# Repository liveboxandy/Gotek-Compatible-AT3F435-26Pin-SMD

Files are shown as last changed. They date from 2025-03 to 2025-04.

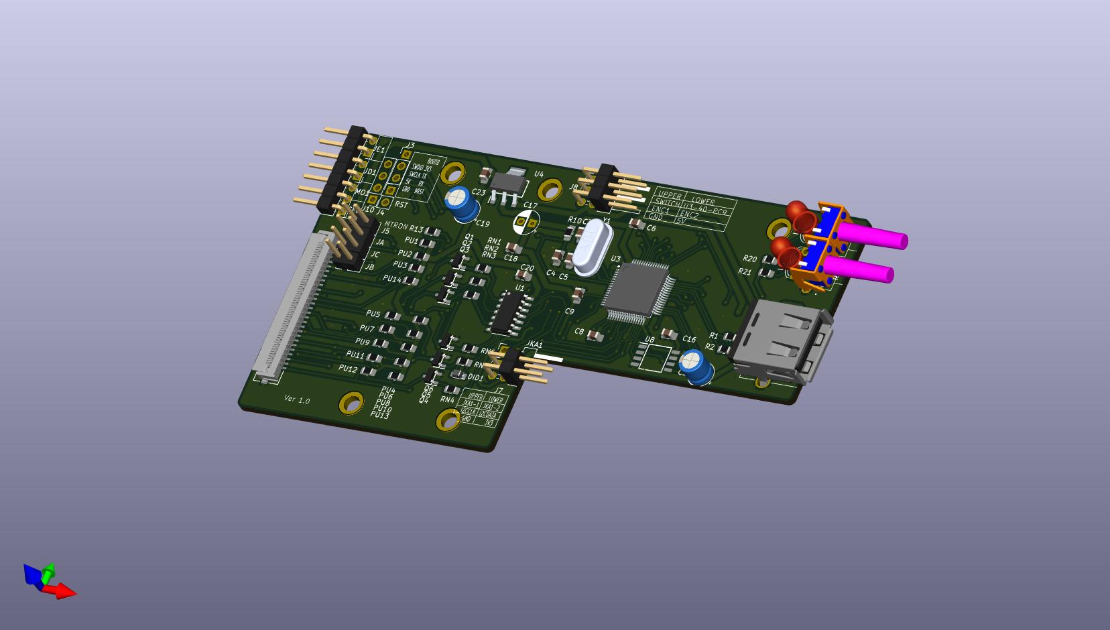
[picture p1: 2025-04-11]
Gotek.jpg

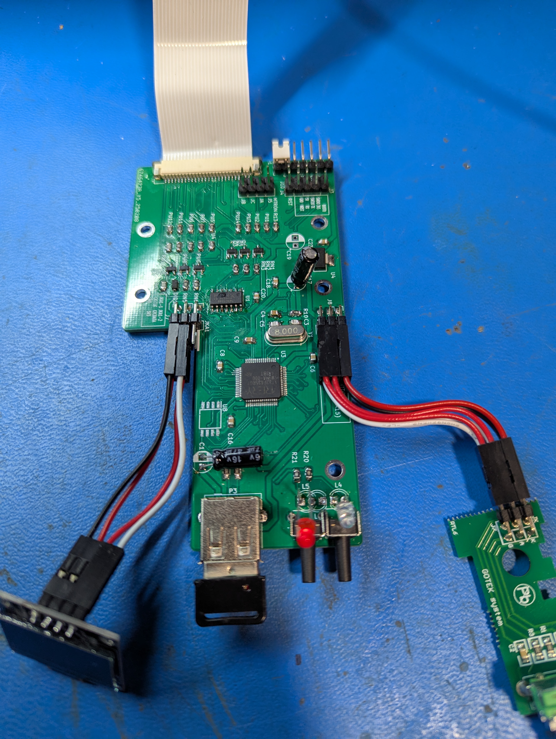
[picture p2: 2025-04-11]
Pictures/AT32F435RGT7.jpg

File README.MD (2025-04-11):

Initial schematic and gerbers for a Gotek(?) compatible with an Artery AT32F435RGT7 chip and a 26 Pin FFC connector.
Used SFRKC30.AT4.35 PCB for most of the schematic and layout but used SFRC2D.B PCB for the 26 Pin FFC connections.
Used photographs and a multimeter along with removing U1 and U3 on the SFRKC30.AT4.35 to get to the traces underneath.
Where possible I followed the original PCB routing of the SFRKC30.AT4.35 but Kicad has some different rules for trace widths (between pins 5&6 of U8 which isn't fitted).

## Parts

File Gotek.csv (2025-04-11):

Source: | W:\Emulators\Spectrum Repair\Gotek Bits\Gotek AT32F435 26 Pin Std Size PCB\Gotek.kicad_sch
Date: | 2025-04-11T10:23:15+0100
Tool: | Eeschema 8.0.9
Generator: | C:\Program Files\KiCad\7.0\bin\scripting\plugins/bom_csv_grouped_by_value.py
Component Count: | 72
Collated Components:
Item | Qty | Reference(s) | Value | LibPart | Footprint | Datasheet | DNP | Arrow Part Number | Arrow Price/Stock | Datasheet | Description | Footprint | Height | Manufacturer_Name | Manufacturer_Part_Number | Mouser Part Number | Mouser Price/Stock | Sim.Device | Sim.Pins
1 | 2 | C1, C19 | 100uF | Device:C_Polarized | Capacitor_THT:CP_Radial_D5.0mm_P2.50mm | ~ |  |  |  | ~ | Polarized capacitor | Capacitor_THT:CP_Radial_D5.0mm_P2.50mm
2 | 2 | C3, C5 | 22pF | Device:C | Capacitor_SMD:C_0805_2012Metric_Pad1.18x1.45mm_HandSolder | ~ |  |  |  | ~ | Unpolarized capacitor | Capacitor_SMD:C_0805_2012Metric_Pad1.18x1.45mm_HandSolder
3 | 8 | C4, C6, C8, C9, C16, C18, C20, C23 | 100nF | Device:C | Capacitor_SMD:C_0805_2012Metric_Pad1.18x1.45mm_HandSolder | ~ |  |  |  | ~ | Unpolarized capacitor | Capacitor_SMD:C_0805_2012Metric_Pad1.18x1.45mm_HandSolder
4 | 1 | C17 | 100uF | Device:C_Polarized | Capacitor_THT:CP_Radial_D5.0mm_P2.50mm | ~ | DNP |  |  | ~ | Polarized capacitor | Capacitor_THT:CP_Radial_D5.0mm_P2.50mm
5 | 1 | DID1 | 1N4148WS | Diode:1N4148WS | Gotek:SODFL2512X90N | https://www.vishay.com/docs/85751/1n4148ws.pdf |  |  |  | https://www.vishay.com/docs/85751/1n4148ws.pdf | 75V 0.15A Fast switching Diode, SOD-323 | Gotek:SODFL2512X90N |  |  |  |  |  | D | 1=K 2=A
6 | 1 | J3 | Conn_01x03_Pin | Connector:Conn_01x03_Pin | Connector_PinHeader_2.54mm:PinHeader_1x03_P2.54mm_Vertical | ~ | DNP |  |  | ~ | Generic connector, single row, 01x03, script generated | Connector_PinHeader_2.54mm:PinHeader_1x03_P2.54mm_Vertical
7 | 1 | J4 | Conn_01x02_Pin | Connector:Conn_01x02_Pin | Connector_PinHeader_2.54mm:PinHeader_1x02_P2.54mm_Vertical | ~ | DNP |  |  | ~ | Generic connector, single row, 01x02, script generated | Connector_PinHeader_2.54mm:PinHeader_1x02_P2.54mm_Vertical
8 | 4 | J5, JA1, JB1, JC1 | Conn_01x02 | Connector:Conn_01x02_Pin | Connector_PinHeader_2.54mm:PinHeader_1x02_P2.54mm_Vertical | ~ |  |  |  | ~ | Generic connector, single row, 01x02, script generated | Connector_PinHeader_2.54mm:PinHeader_1x02_P2.54mm_Vertical
9 | 1 | J7 | OLED | Connector:Conn_01x04_Pin | Connector_PinHeader_2.54mm:PinHeader_2x02_P2.54mm_Horizontal | ~ |  |  |  | ~ | Generic connector, single row, 01x04, script generated | Connector_PinHeader_2.54mm:PinHeader_2x02_P2.54mm_Horizontal
10 | 1 | J8 | RotaryEncoder | Connector:Conn_01x04_Pin | Connector_PinHeader_2.54mm:PinHeader_2x02_P2.54mm_Horizontal | ~ |  |  |  | ~ | Generic connector, single row, 01x04, script generated | Connector_PinHeader_2.54mm:PinHeader_2x02_P2.54mm_Horizontal
11 | 1 | J10 | Conn_01x04_Pin | Connector:Conn_01x04_Pin | Connector_PinHeader_2.54mm:PinHeader_1x04_P2.54mm_Vertical | ~ | DNP |  |  | ~ | Generic connector, single row, 01x04, script generated | Connector_PinHeader_2.54mm:PinHeader_1x04_P2.54mm_Vertical
12 | 2 | JD1, JE1 | Conn_01x02_Pin | Connector:Conn_01x02_Pin | Connector_PinHeader_2.54mm:PinHeader_1x02_P2.54mm_Horizontal | ~ |  |  |  | ~ | Generic connector, single row, 01x02, script generated | Connector_PinHeader_2.54mm:PinHeader_1x02_P2.54mm_Horizontal
13 | 1 | JK1 | Conn_01x02 | Connector:Conn_01x02_Pin | Connector_PinHeader_2.54mm:PinHeader_2x01_P2.54mm_Horizontal | ~ |  |  |  | ~ | Generic connector, single row, 01x02, script generated | Connector_PinHeader_2.54mm:PinHeader_2x01_P2.54mm_Horizontal
14 | 1 | JKA1 | Conn_01x02 | Connector:Conn_01x02_Pin | Connector_PinHeader_2.54mm:PinHeader_2x01_P2.54mm_Horizontal | ~ | DNP |  |  | ~ | Generic connector, single row, 01x02, script generated | Connector_PinHeader_2.54mm:PinHeader_2x01_P2.54mm_Horizontal
15 | 1 | L3 | LED GREEN | Device:LED | LED_THT:LED_D4.0mm | ~ | DNP |  |  | ~ | Light emitting diode | LED_THT:LED_D4.0mm
16 | 1 | L4 | LED GREEN | Device:LED | LED_THT:LED_D4.0mm | ~ |  |  |  | ~ | Light emitting diode | LED_THT:LED_D4.0mm
17 | 1 | L5 | LED RED | Device:LED | LED_THT:LED_D4.0mm | ~ |  |  |  | ~ | Light emitting diode | LED_THT:LED_D4.0mm
18 | 1 | MO1 | Conn_01x03_Pin | Connector:Conn_01x03_Pin | Connector_PinHeader_2.54mm:PinHeader_1x03_P2.54mm_Horizontal | ~ |  |  |  | ~ | Generic connector, single row, 01x03, script generated | Connector_PinHeader_2.54mm:PinHeader_1x03_P2.54mm_Horizontal
19 | 1 | P1 | 2005280260 | Gotek:2005280260 | Gotek:MOLEX_CON_2005280260 | 2005280260 |  |  |  | 2005280260 |  | Gotek:MOLEX_CON_2005280260
20 | 1 | P3 | USB_A | Connector:USB_A | Connector_USB:USB_A_Molex_67643_Horizontal | ~ |  |  |  | ~ | USB Type A connector | Connector_USB:USB_A_Molex_67643_Horizontal
21 | 21 | PU1, PU2, PU3, PU4, PU5, PU6, PU7, PU8, PU9, PU10, PU11, PU12, PU13, PU14, R20, RN1, RN2, RN3, RN4, RN5, RN6 | 1K | Device:R | Resistor_SMD:R_0805_2012Metric_Pad1.20x1.40mm_HandSolder | ~ |  |  |  | ~ | Resistor | Resistor_SMD:R_0805_2012Metric_Pad1.20x1.40mm_HandSolder
22 | 6 | Q1, Q2, Q3, Q4, Q5, Q6 | PMBT2222A,215 | Gotek:PMBT2222A,215 | Gotek:SOT95P280X130-3N | https://assets.nexperia.com/documents/data-sheet/PMBT2222A.pdf |  |  |  | https://assets.nexperia.com/documents/data-sheet/PMBT2222A.pdf | PMBT2222; PMBT2222A - NPN switching transistors | Gotek:SOT95P280X130-3N | 1.1 | Nexperia | PMBT2222A,215 | 771-PMBT2222A-T/R | https://www.mouser.co.uk/ProductDetail/Nexperia/PMBT2222A215?qs=LOCUfHb8d9u7n2jbGrJFWg%3D%3D
23 | 2 | R1, R2 | 22R | Device:R | Resistor_SMD:R_0805_2012Metric_Pad1.20x1.40mm_HandSolder | ~ |  |  |  | ~ | Resistor | Resistor_SMD:R_0805_2012Metric_Pad1.20x1.40mm_HandSolder
24 | 2 | R10, R13 | 4K7 | Device:R | Resistor_SMD:R_0805_2012Metric_Pad1.20x1.40mm_HandSolder | ~ |  |  |  | ~ | Resistor | Resistor_SMD:R_0805_2012Metric_Pad1.20x1.40mm_HandSolder
25 | 1 | R21 | 12K | Device:R | Resistor_SMD:R_0805_2012Metric_Pad1.20x1.40mm_HandSolder | ~ |  |  |  | ~ | Resistor | Resistor_SMD:R_0805_2012Metric_Pad1.20x1.40mm_HandSolder
26 | 2 | S3, S4 | SKHHANA010 | Gotek:SKHHANA010 | Gotek:SKHHLQA010 | https://www.mouser.co.uk/datasheet/2/15/SKHH-1370651.pdf |  |  |  | https://www.mouser.co.uk/datasheet/2/15/SKHH-1370651.pdf | Tact switch,PCB,SPST,black,0.98N o/force Black Stem Tactile Switch, SPST-NO 50 mA 9.5mm | Gotek:SKHHLQA010 |  | ALPS Electric | SKHHANA010 | 688-SKHHAN | https://www.mouser.co.uk/ProductDetail/Alps-Alpine/SKHHANA010?qs=seHrhfPpLDzbQApxfd3mfQ%3D%3D
27 | 1 | U1 | 74AHC04 | 74xx:74AHC04 | Package_SO:SO-14_3.9x8.65mm_P1.27mm | https://assets.nexperia.com/documents/data-sheet/74AHC_AHCT04.pdf |  |  |  | https://assets.nexperia.com/documents/data-sheet/74AHC_AHCT04.pdf | Hex Inverter | Package_SO:SO-14_3.9x8.65mm_P1.27mm
28 | 1 | U3 | AT32F435RGT7 | Gotek:AT32F435RxT7-SQ | Gotek:QFP50P1200X1200X160-64N | https://www.arterychip.com/file/download/1977 |  |  |  | https://www.arterychip.com/file/download/1977 | 32-Bit FLASH ARM Cortex-M4 200MHz 2.6V ~ 3.6V LQFP-64 ARTERY Mcu RoHS | Gotek:QFP50P1200X1200X160-64N | 1.6 | Artery | AT32F435RGT7
29 | 1 | U4 | AMS1117-3.3 | Gotek:ams1117-3.3v | Gotek:SOT229P700X180-4N | http://www.advanced-monolithic.com/pdf/ds1117.pdf |  |  |  | http://www.advanced-monolithic.com/pdf/ds1117.pdf | 1A LOW DROPOUT VOLTAGE REGULATOR, SOT-223 | Gotek:SOT229P700X180-4N | 1.8 | Advanced Monolithic Systems | ams1117-3.3v
30 | 1 | U8 | SST25VF016B-50-4C-S2AF | Gotek:SST25VF016B-50-4C-S2AF | Gotek:SOIC127P790X216-8N | https://ww1.microchip.com/downloads/en/DeviceDoc/20005044C.pdf | DNP |  |  | https://ww1.microchip.com/downloads/en/DeviceDoc/20005044C.pdf | MICROCHIP - SST25VF016B-50-4C-S2AF - Flash Memory, Serial NOR, 16 Mbit, SPI, SOIC, 8 Pins | Gotek:SOIC127P790X216-8N | 2.16 | Microchip | SST25VF016B-50-4C-S2AF | 579-25VF016B504CS2AF | https://www.mouser.co.uk/ProductDetail/Microchip-Technology-Atmel/SST25VF016B-50-4C-S2AF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
31 | 1 | Y1 | 8Mhz | Device:Crystal | Crystal:Crystal_HC18-U_Vertical | ~ |  |  |  | ~ | Two pin crystal | Crystal:Crystal_HC18-U_Vertical

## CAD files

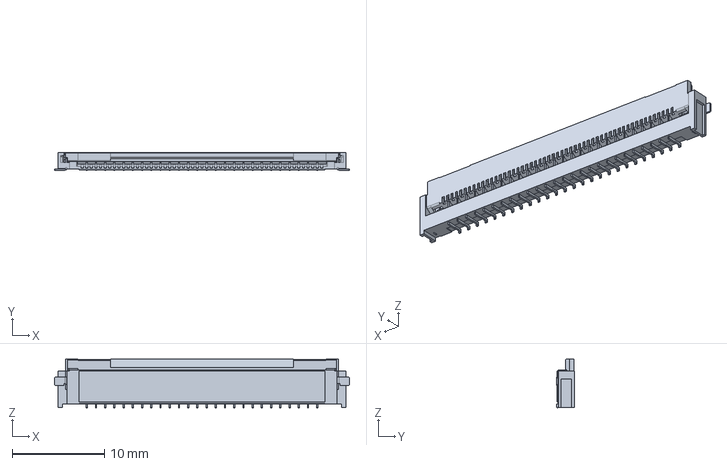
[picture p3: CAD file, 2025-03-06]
MOD/Molex 2005280260.stp
32.0 x 1.90 x 5.30 mm

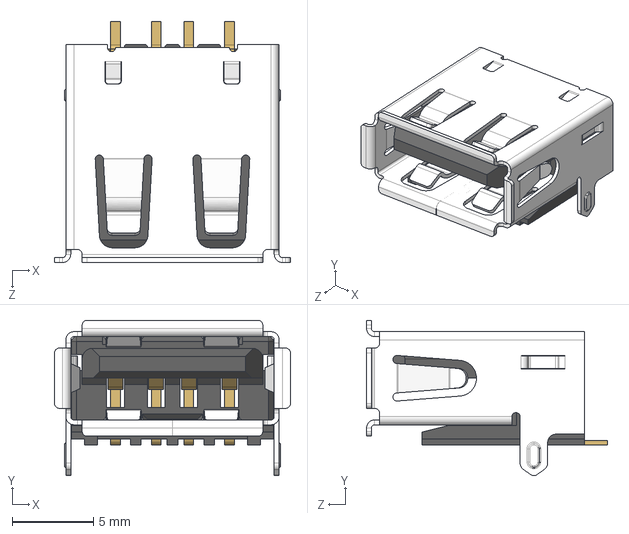
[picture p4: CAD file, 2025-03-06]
MOD/USB1046-GF-0190-L-B-A.stp
14.5 x 9.55 x 14.8 mm

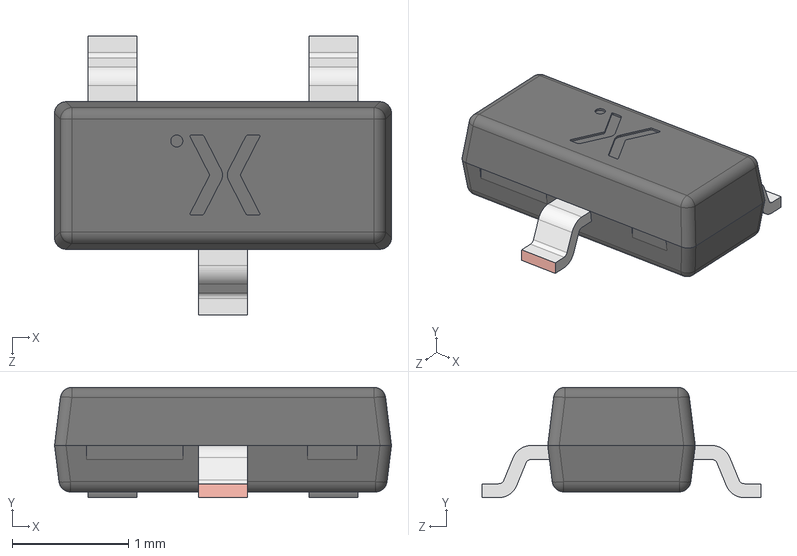
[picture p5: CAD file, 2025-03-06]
MOD/PMBT2222A,215.stp
2.90 x 0.95 x 2.40 mm
SOT23 lower body
SOT23 Lead x 3
SOT23 Upper body

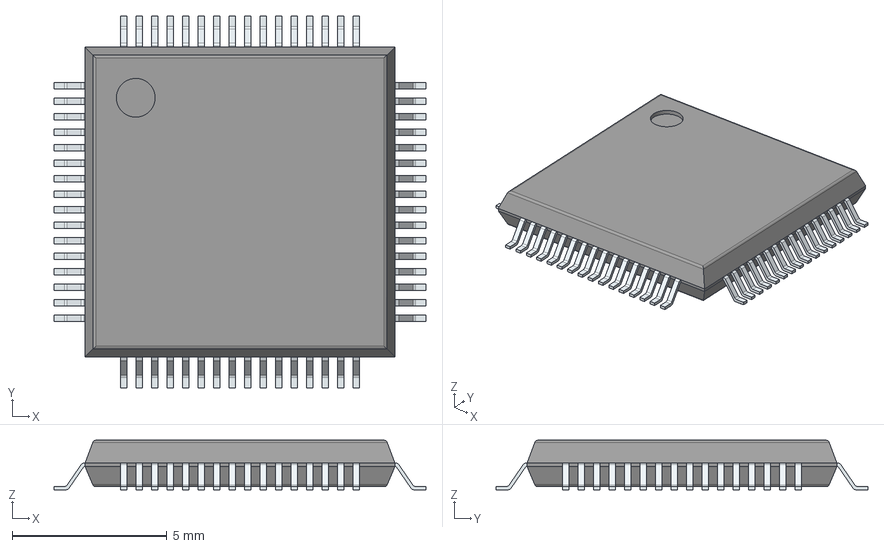
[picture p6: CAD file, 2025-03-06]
MOD/AT32F415RxT7.stp
12.0 x 12.0 x 1.60 mm
PinsArrayLR
PinsArrayTB

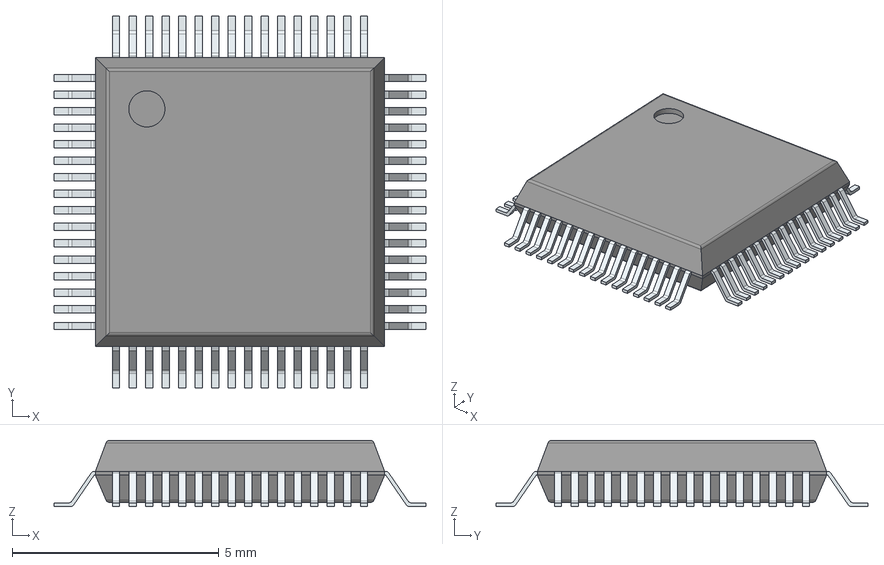
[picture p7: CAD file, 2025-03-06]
MOD/at32f415rct7.stp
9.00 x 9.00 x 1.60 mm
PinsArrayLR
PinsArrayTB

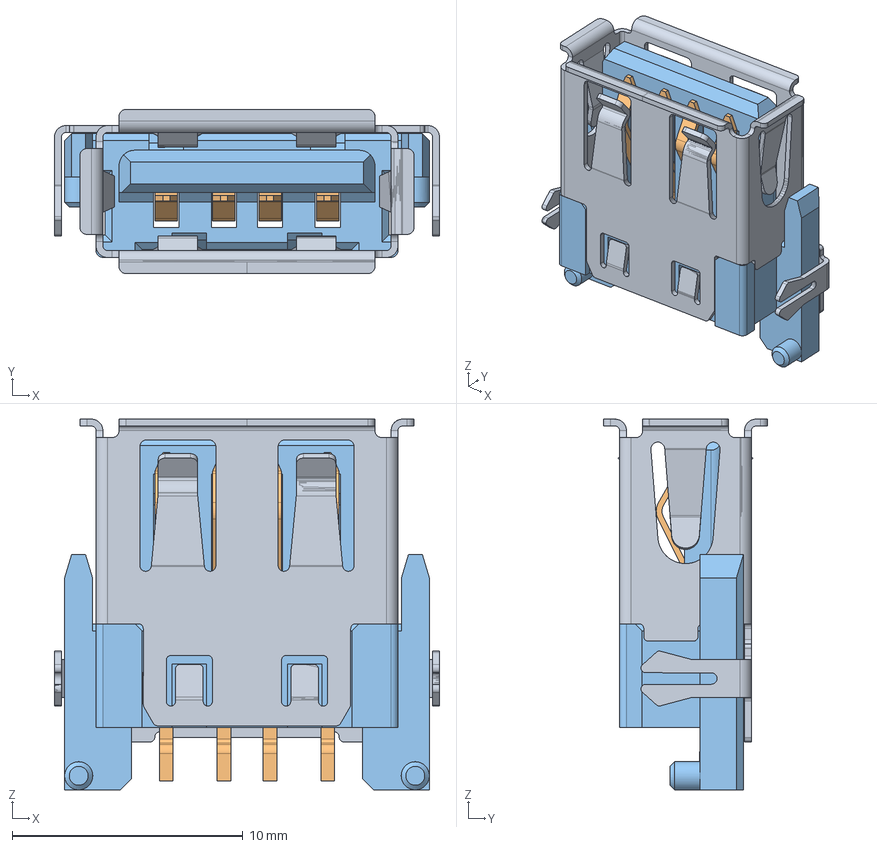
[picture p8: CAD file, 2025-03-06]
MOD/USB1055-GF-L-A.stp
16.7 x 7.12 x 16.1 mm
USB1055-GF-L-A_PART8
USB1055-GF-L-A_PART7
USB1055-GF-L-A_PART6
USB1055-GF-L-A_PART5
USB1055-GF-L-A_PART4
USB1055-GF-L-A_PART3
USB1055-GF-L-A_PART2
USB1055-GF-L-A_PART1

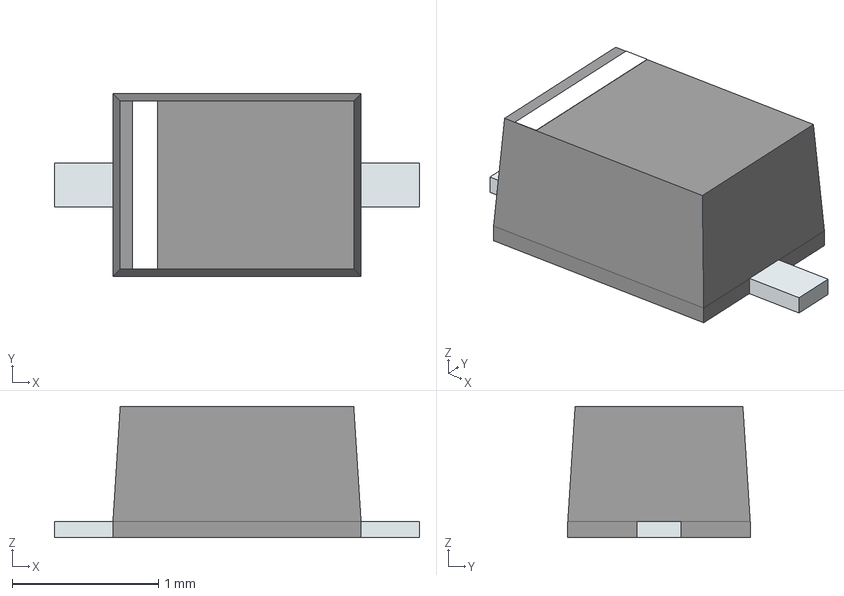
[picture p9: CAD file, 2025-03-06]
MOD/1N4148WS.stp
2.50 x 1.25 x 0.9 mm
PinKIdent
PinK
PinA

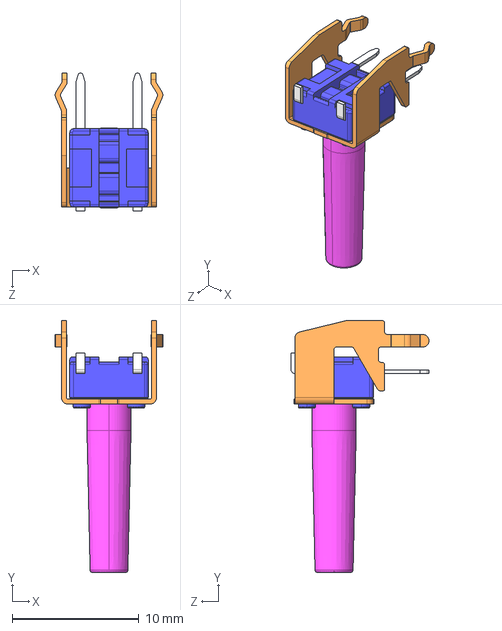
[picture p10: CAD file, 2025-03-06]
MOD/SKHHNK.STEP
8.50 x 19.9 x 10.9 mm

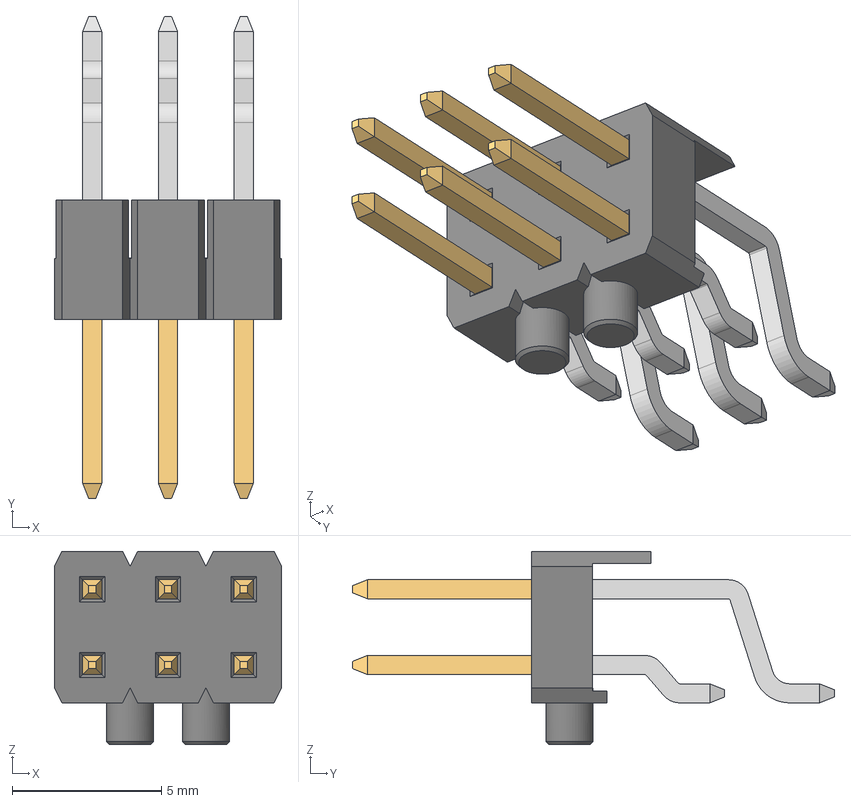
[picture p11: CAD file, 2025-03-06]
MOD/6101XX249121_610106249121.step
7.62 x 16.2 x 6.48 mm
6100xx249121_PIN LONGUE x 3
6100xx249121_PIN COURTE x 3

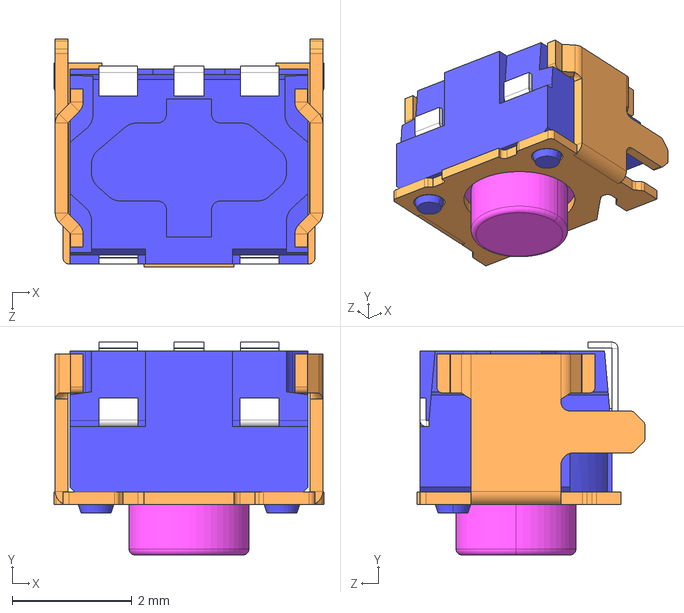
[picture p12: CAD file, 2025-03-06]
MOD/SKRTLAE010.stp
4.50 x 3.55 x 3.80 mm

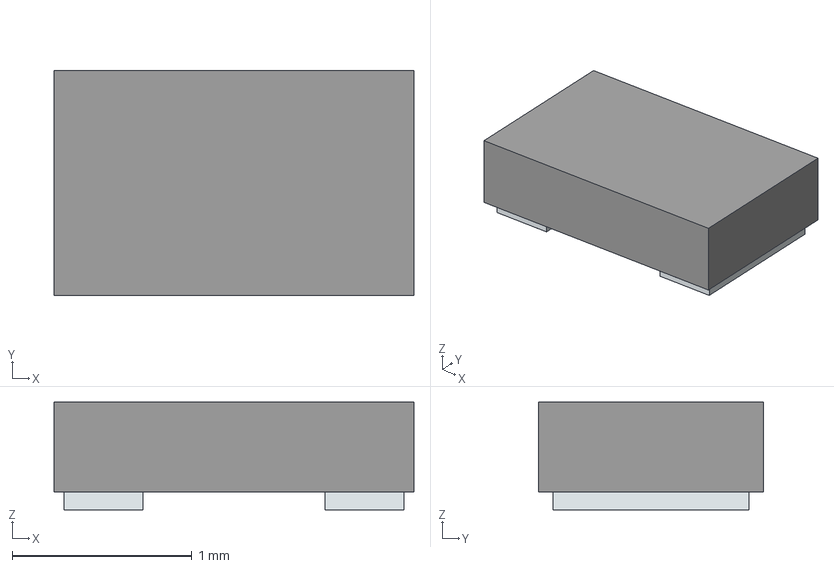
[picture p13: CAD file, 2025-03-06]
MOD/HSMC-C177.stp
2.00 x 1.25 x 0.6 mm
Pins

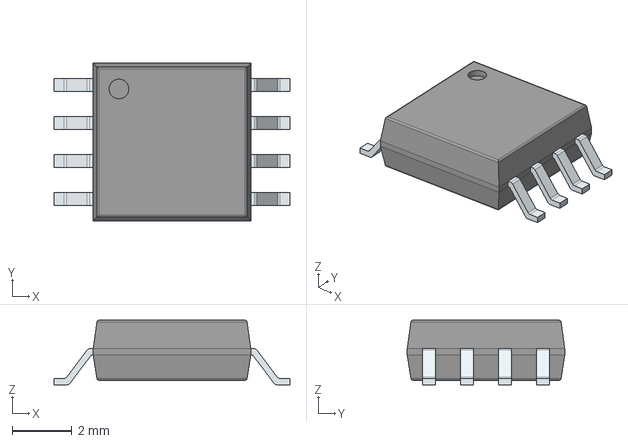
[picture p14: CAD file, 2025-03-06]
MOD/SST25VF016B-50-4C-S2AF.stp
7.90 x 5.28 x 2.16 mm
PinsArrayLR

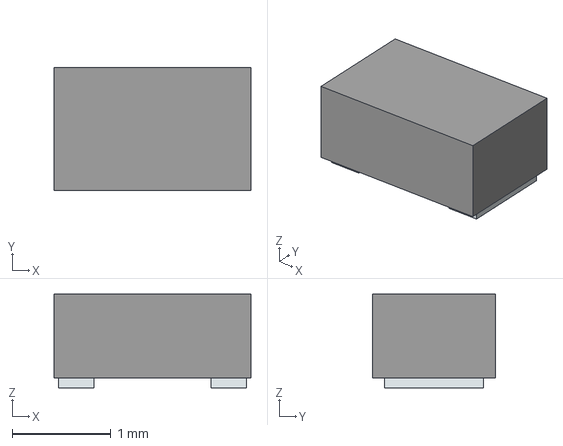
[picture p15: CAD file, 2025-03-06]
MOD/APT2012PGW.stp
2.00 x 1.25 x 0.95 mm
Pins

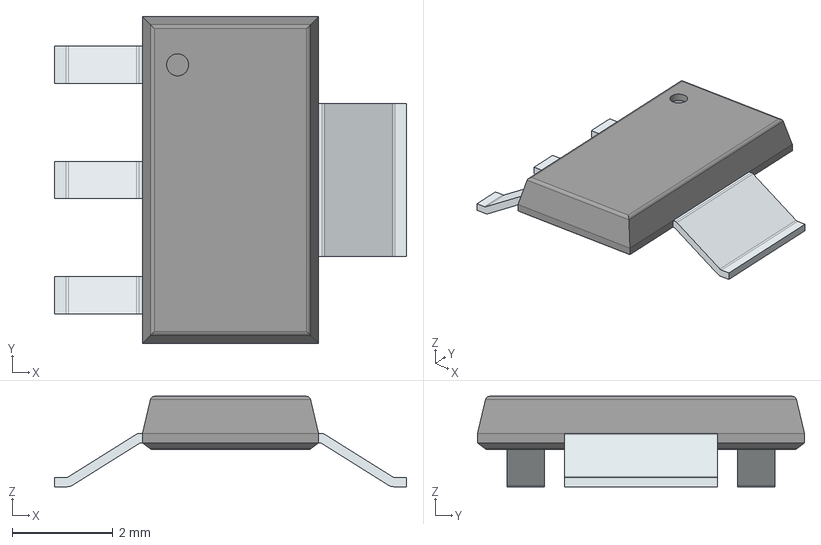
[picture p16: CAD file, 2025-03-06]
MOD/ams1117-3.3v.stp
7.00 x 6.50 x 1.80 mm
PinsArrayL
FilletPinR

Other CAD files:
MOD/SKHHNH.stp
MOD/SKRTLBE010.stp
MOD/LFXTAL050985Bulk.stp
MOD/171826-4.stp
MOD/ABL-8.000MHZ-B2.stp
MOD/M20-8750442.stp
MOD/M20-8760442P.stp
MOD/M20-8760542P.stp
MOD/M20-8890245R.stp
MOD/M20-8890345R.stp
MOD/M20-8900705.stp
MOD/SKHHNHA010.stp

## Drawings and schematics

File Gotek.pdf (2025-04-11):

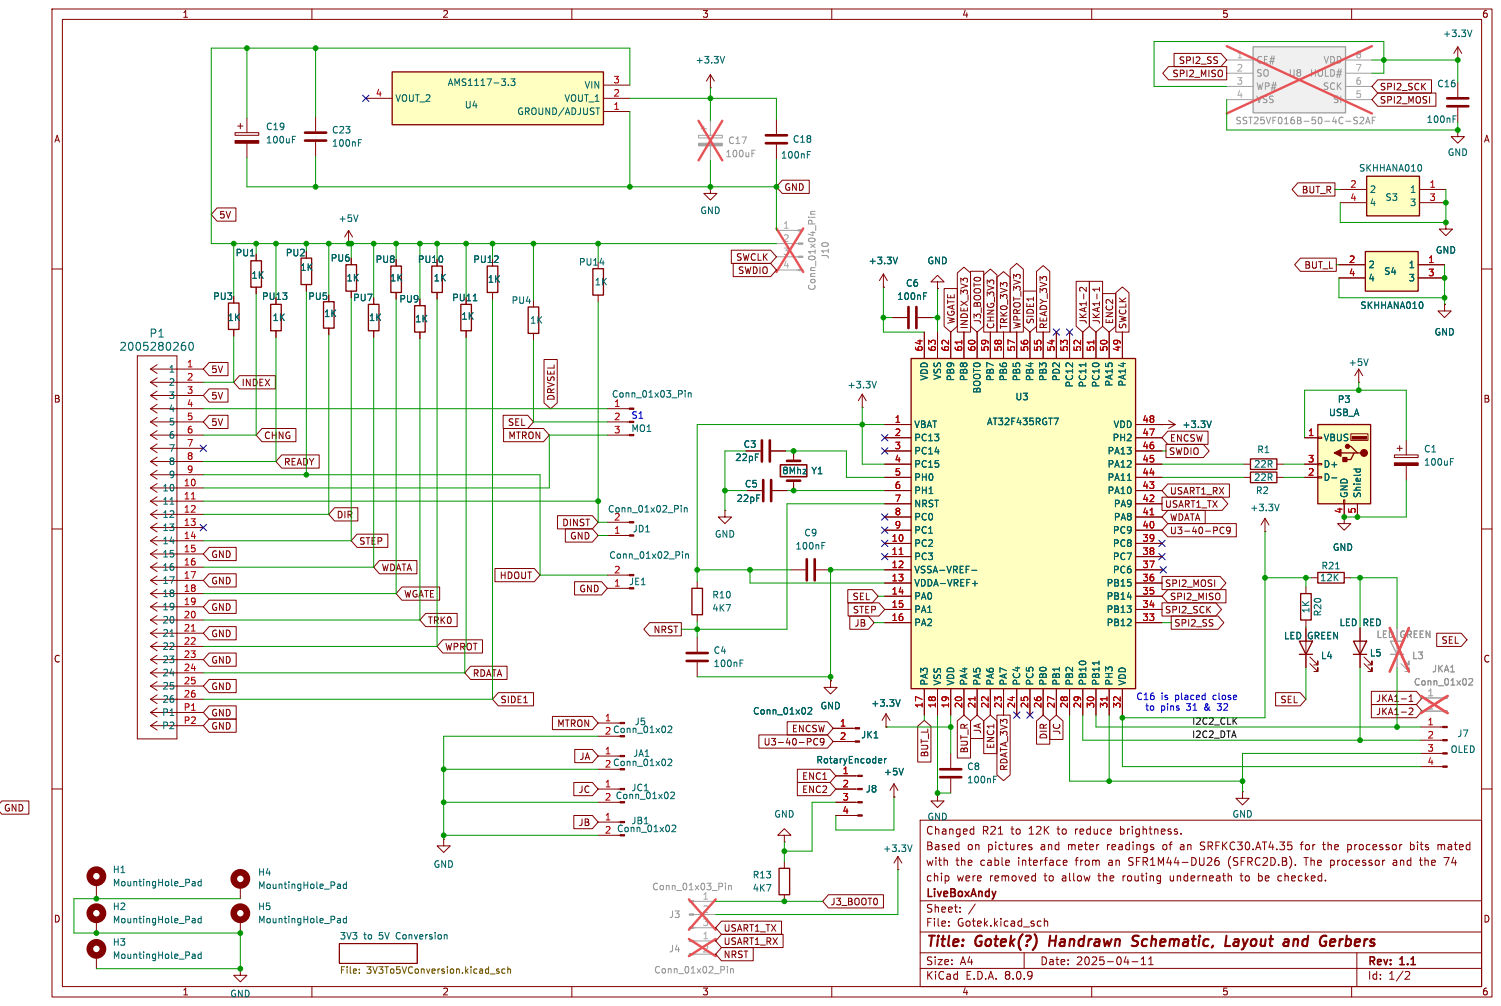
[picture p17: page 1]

File: Gotek.kicad_sch Sheet: / LiveBoxAndy

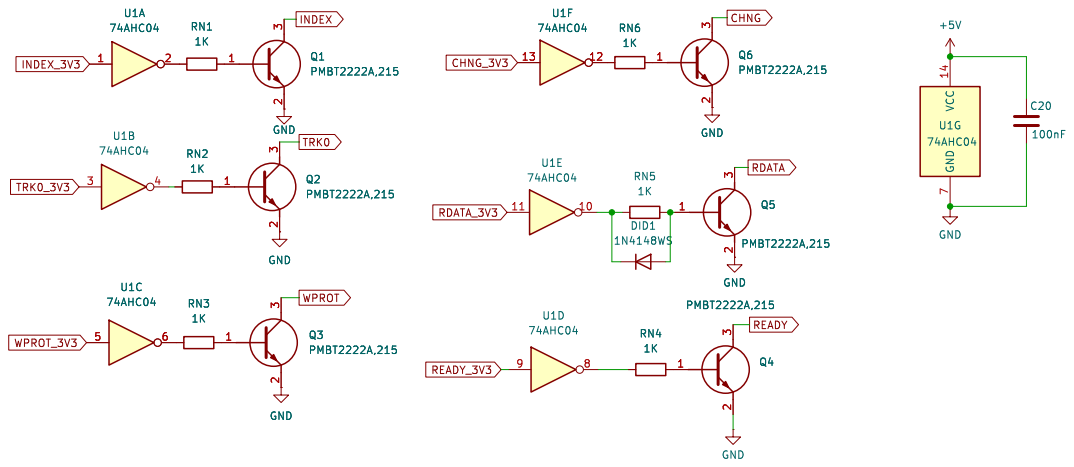
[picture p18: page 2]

File: 3V3To5VConversion.kicad_sch Sheet: /3V3 to 5V Conversion/ LiveBoxAndy

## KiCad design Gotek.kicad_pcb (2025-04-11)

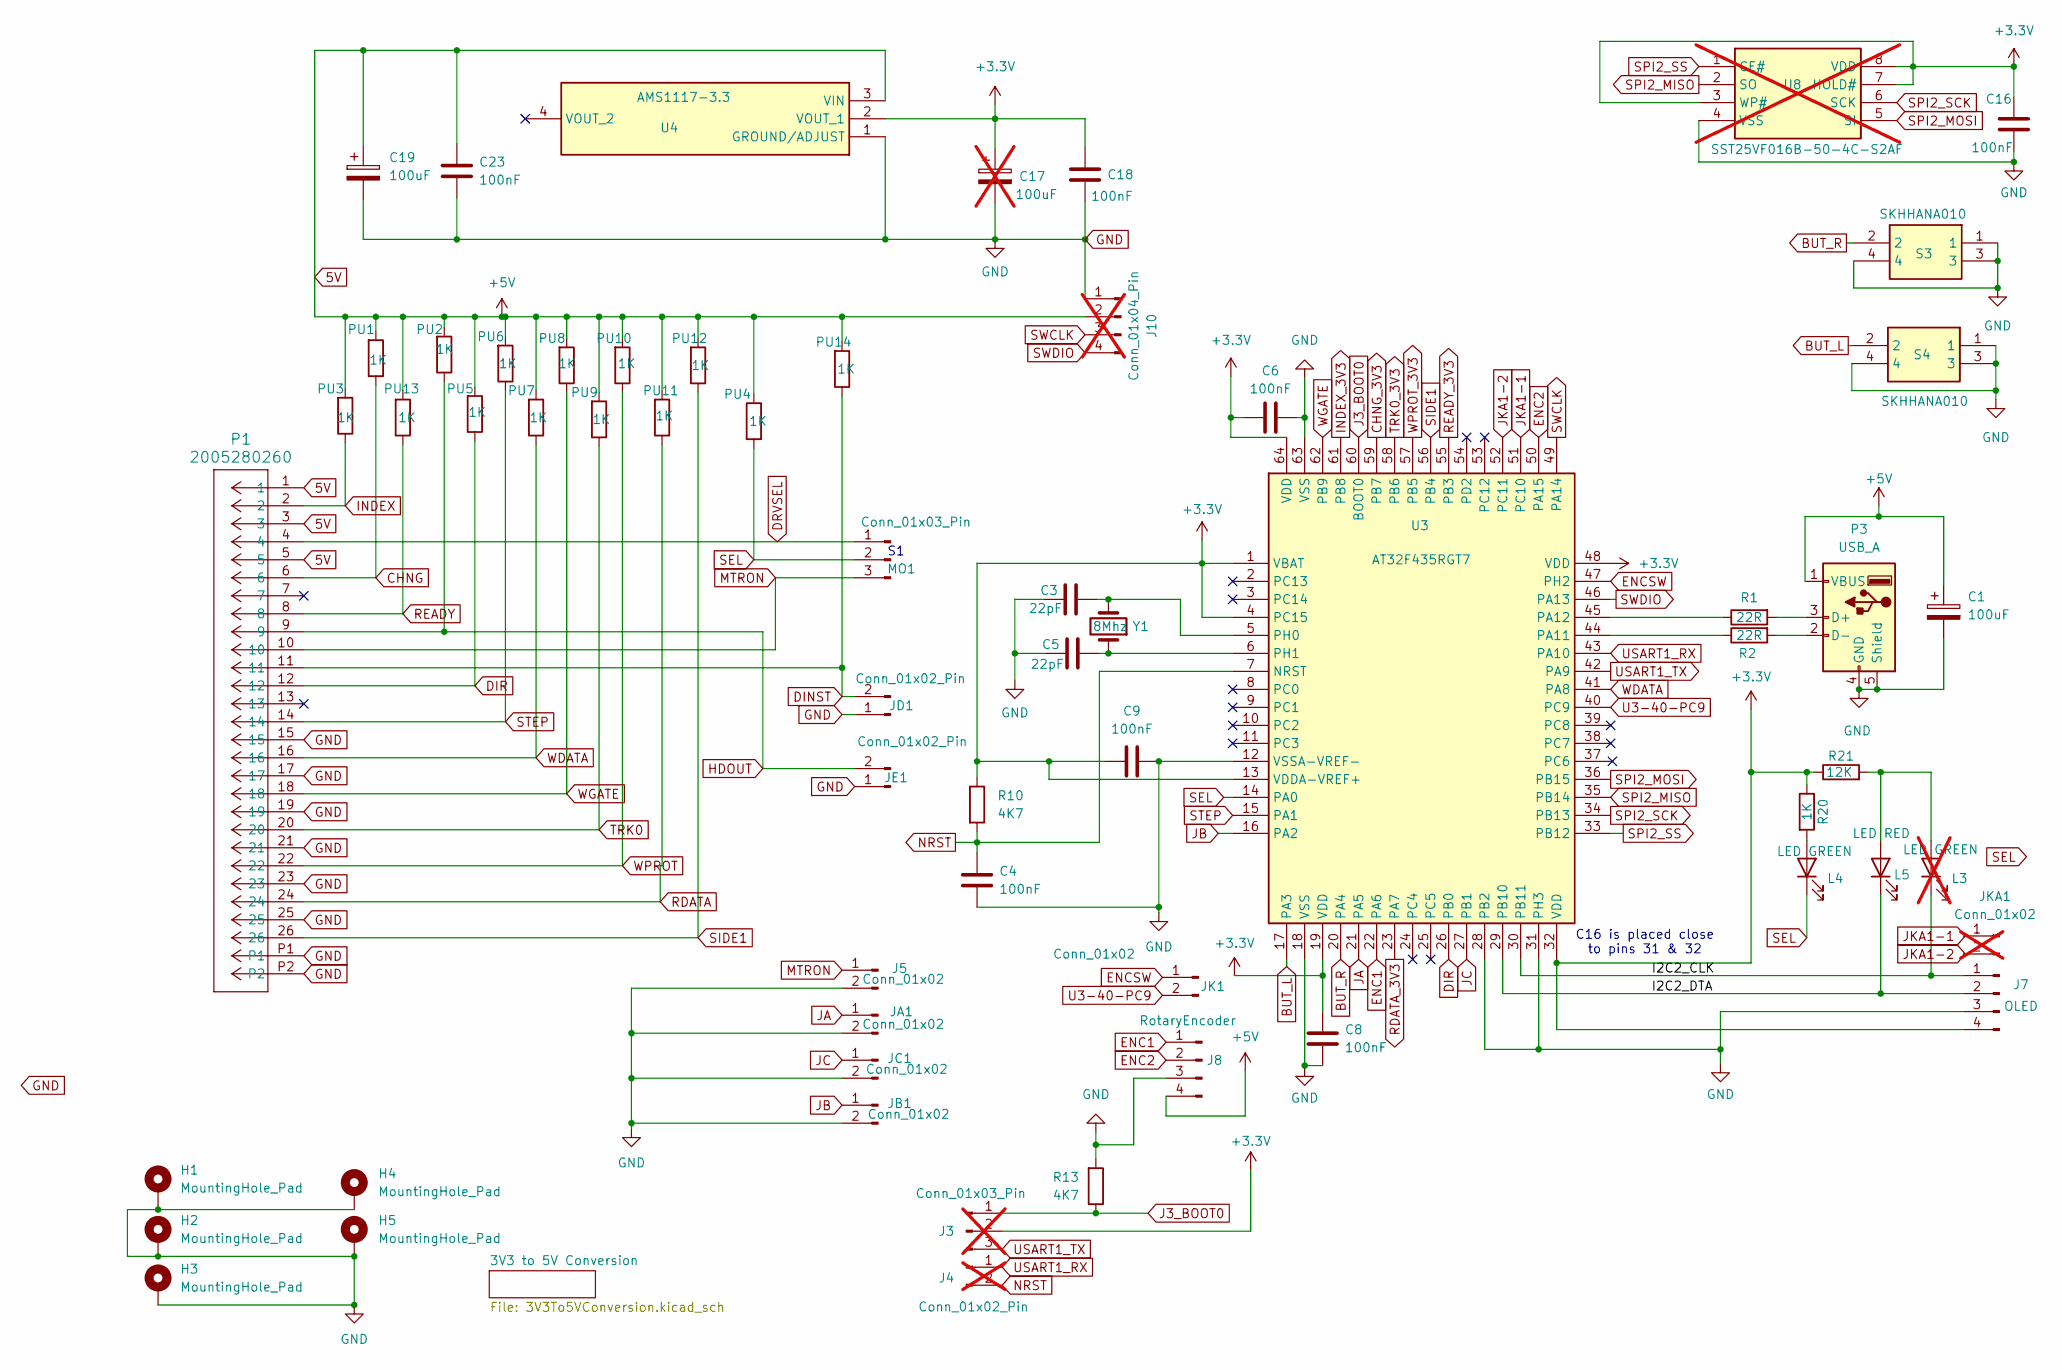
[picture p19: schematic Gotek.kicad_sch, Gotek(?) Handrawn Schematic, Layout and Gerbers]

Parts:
C1, C19: 100uF; CP_Radial_D5.0mm_P2.50mm
C3, C5: 22pF; C_0805_2012Metric_Pad1.18x1.45mm_HandSolder
C4, C6, C8, C9, C16, C18, C23: 100nF; C_0805_2012Metric_Pad1.18x1.45mm_HandSolder
C17: 100uF; CP_Radial_D5.0mm_P2.50mm; not fitted
H1, H2, H3, H4, H5: MountingHole_Pad; MountingHole_M3_Pad
J3: Conn_01x03_Pin; PinHeader_1x03_P2.54mm_Vertical; not fitted
J4: Conn_01x02_Pin; PinHeader_1x02_P2.54mm_Vertical; not fitted
J5: Conn_01x02; PinHeader_1x02_P2.54mm_Vertical
J7: OLED; PinHeader_2x02_P2.54mm_Horizontal
J8: RotaryEncoder; PinHeader_2x02_P2.54mm_Horizontal
J10: Conn_01x04_Pin; PinHeader_1x04_P2.54mm_Vertical; not fitted
JA1: Conn_01x02; PinHeader_1x02_P2.54mm_Vertical
JB1: Conn_01x02; PinHeader_1x02_P2.54mm_Vertical
JC1: Conn_01x02; PinHeader_1x02_P2.54mm_Vertical
JD1: Conn_01x02_Pin; PinHeader_1x02_P2.54mm_Horizontal
JE1: Conn_01x02_Pin; PinHeader_1x02_P2.54mm_Horizontal
JK1: Conn_01x02; PinHeader_2x01_P2.54mm_Horizontal
JKA1: Conn_01x02; PinHeader_2x01_P2.54mm_Horizontal; not fitted
L3: LED GREEN; LED_D4.0mm; not fitted
L4: LED GREEN; LED_D4.0mm
L5: LED RED; LED_D4.0mm
MO1: Conn_01x03_Pin; PinHeader_1x03_P2.54mm_Horizontal
P1: 2005280260; MOLEX_CON_2005280260
P3: USB_A; USB_A_Molex_67643_Horizontal
PU1, PU2, PU3, PU4, PU5, PU6, PU7, PU8, PU9, PU10, PU11, PU12, PU13, PU14: 1K; R_0805_2012Metric_Pad1.20x1.40mm_HandSolder
R1, R2: 22R; R_0805_2012Metric_Pad1.20x1.40mm_HandSolder
R10, R13: 4K7; R_0805_2012Metric_Pad1.20x1.40mm_HandSolder
R20: 1K; R_0805_2012Metric_Pad1.20x1.40mm_HandSolder
R21: 12K; R_0805_2012Metric_Pad1.20x1.40mm_HandSolder
S3, S4: SKHHANA010; SKHHLQA010; Mouser Part Number 688-SKHHAN
U3: AT32F435RGT7; QFP50P1200X1200X160-64N; Manufacturer_Part_Number AT32F435RGT7
U4: AMS1117-3.3; SOT229P700X180-4N; Manufacturer_Part_Number ams1117-3.3v
U8: SST25VF016B-50-4C-S2AF; SOIC127P790X216-8N; Mouser Part Number 579-25VF016B504CS2AF; not fitted
Y1: 8Mhz; Crystal_HC18-U_Vertical

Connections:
5V: C1.1, C19.1, C23.1, J8.4, J10.2, P1.1, P1.3, P1.5, P3.1 (VBUS), PU1.2, PU2.2, PU3.2, PU4.1, PU5.2, PU6.2, PU7.2, PU8.2, PU9.2, PU10.2, PU11.2, PU12.2, PU13.2, PU14.2, U4.3 (VIN); also elsewhere on the board
+3.3V: C6.1, C8.1, C9.2, C16.2, C17.1, C18.2, J3.2, J7.4, R10.1, R20.1, R21.1, U3.1 (VBAT), U3.4 (PC15), U3.13 (VDDA-VREF+), U3.19 (VDD), U3.32 (VDD), U3.48 (VDD), U3.64 (VDD), U4.2 (VOUT_1), U8.3 (WP#), U8.7 (HOLD#), U8.8 (VDD)
/I2C2_CLK: J7.1, L3.1 (K), U3.30 (PB11)
/I2C2_DTA: J7.2, L5.1 (K), U3.29 (PB10)
BUT_L: S4.2, U3.17 (PA3)
BUT_R: S3.2, U3.20 (PA4)
CHNG: P1.6, PU1.1; also elsewhere on the board
CHNG_3V3: U3.59 (PB7); also elsewhere on the board
DINST: JD1.2, P1.11, PU14.1
DIR: P1.12, PU5.1, U3.26 (PB0)
DRVSEL: MO1.1, P1.4
ENC1: J8.1, U3.22 (PA6)
ENC2: J8.2, U3.50 (PA15)
ENCSW: JK1.1, U3.47 (PH2)
GND: C1.2, C3.1, C4.2, C5.2, C6.2, C8.2, C9.1, C16.1, C17.2, C18.1, C19.2, C23.2, H1.1, H2.1, H3.1, H4.1, H5.1, J5.2, J7.3, J8.3, J10.1, JA1.2, JB1.2, JC1.2, JD1.1, JE1.1, P1.15, P1.17, P1.19, P1.21, P1.23, P1.25, P1.P1, P1.P2, P3.4 (GND), P3.5 (Shield), R13.2, S3.1, S3.3, S3.4, S4.1, S4.3, S4.4, U3.12 (VSSA-VREF-), U3.18 (VSS), U3.28 (PB2), U3.31 (PH3), U3.63 (VSS), U4.1 (GROUND/ADJUST), U8.4 (VSS); also elsewhere on the board
HDOUT: JE1.2, P1.9, PU2.1
INDEX: P1.2, PU3.1; also elsewhere on the board
INDEX_3V3: U3.61 (PB8); also elsewhere on the board
J3_BOOT0: J3.1, R13.1, U3.60 (BOOT0)
JA: JA1.1, U3.21 (PA5)
JB: JB1.1, U3.16 (PA2)
JC: JC1.1, U3.27 (PB1)
JKA1-1: JKA1.1, U3.51 (PC10)
JKA1-2: JKA1.2, U3.52 (PC11)
MTRON: J5.1, MO1.3, P1.10
NRST: C4.1, J4.2, R10.2, U3.7 (NRST)
unnamed: L3.2 (A), L5.2 (A), R21.2
unnamed: L4.2 (A), R20.2
unnamed: P3.3 (D+), R1.2
unnamed: P3.2 (D-), R2.2
unnamed: R2.1, U3.44 (PA11)
unnamed: R1.1, U3.45 (PA12)
unnamed: C3.2, U3.5 (PH0), Y1.2
unnamed: C5.1, U3.6 (PH1), Y1.1
RDATA: P1.24, PU11.1; also elsewhere on the board
RDATA_3V3: U3.23 (PA7); also elsewhere on the board
READY: P1.8, PU13.1; also elsewhere on the board
READY_3V3: U3.55 (PB3); also elsewhere on the board
SEL: L4.1 (K), MO1.2, PU4.2, U3.14 (PA0)
SIDE1: P1.26, PU12.1, U3.56 (PB4)
SPI2_MISO: U3.35 (PB14), U8.2 (SO)
SPI2_MOSI: U3.36 (PB15), U8.5 (SI)
SPI2_SCK: U3.34 (PB13), U8.6 (SCK)
SPI2_SS: U3.33 (PB12), U8.1 (CE#)
STEP: P1.14, PU6.1, U3.15 (PA1)
SWCLK: J10.3, U3.49 (PA14)
SWDIO: J10.4, U3.46 (PA13)
TRK0: P1.20, PU9.1; also elsewhere on the board
TRK0_3V3: U3.58 (PB6); also elsewhere on the board
U3-40-PC9: JK1.2, U3.40 (PC9)
USART1_RX: J4.1, U3.43 (PA10)
USART1_TX: J3.3, U3.42 (PA9)
WDATA: P1.16, PU7.1, U3.41 (PA8)
WGATE: P1.18, PU8.1, U3.62 (PB9)
WPROT: P1.22, PU10.1; also elsewhere on the board
WPROT_3V3: U3.57 (PB5); also elsewhere on the board

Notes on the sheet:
C16 is placed close to pins 31 & 32

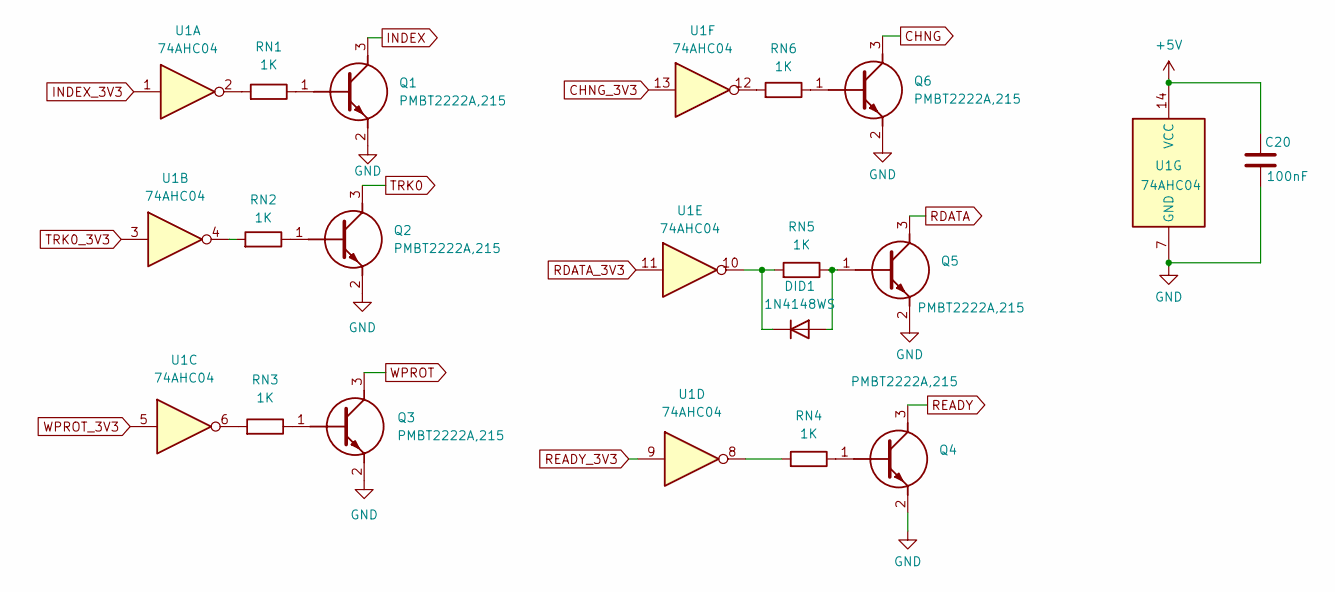
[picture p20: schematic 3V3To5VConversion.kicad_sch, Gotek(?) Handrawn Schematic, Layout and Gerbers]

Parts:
C20: 100nF; C_0805_2012Metric_Pad1.18x1.45mm_HandSolder
DID1: 1N4148WS; SODFL2512X90N
Q1, Q2, Q3, Q4, Q5, Q6: PMBT2222A,215; SOT95P280X130-3N; Mouser Part Number 771-PMBT2222A-T/R
RN1, RN2, RN3, RN4, RN5, RN6: 1K; R_0805_2012Metric_Pad1.20x1.40mm_HandSolder
U1: 74AHC04; SO-14_3.9x8.65mm_P1.27mm

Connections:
5V: C20.2, U1.14 (VCC); also elsewhere on the board
CHNG: Q6.3 (C); also elsewhere on the board
CHNG_3V3: U1.13; also elsewhere on the board
GND: C20.1, Q1.2 (E), Q2.2 (E), Q3.2 (E), Q4.2 (E), Q5.2 (E), Q6.2 (E), U1.7 (GND); also elsewhere on the board
INDEX: Q1.3 (C); also elsewhere on the board
INDEX_3V3: U1.1; also elsewhere on the board
unnamed: DID1.2 (A), Q5.1 (B), RN5.1
unnamed: DID1.1 (K), RN5.2, U1.10
unnamed: Q1.1 (B), RN1.1
unnamed: Q2.1 (B), RN2.1
unnamed: Q3.1 (B), RN3.1
unnamed: Q4.1 (B), RN4.1
unnamed: Q6.1 (B), RN6.1
unnamed: RN1.2, U1.2
unnamed: RN2.2, U1.4
unnamed: RN3.2, U1.6
unnamed: RN4.2, U1.8
unnamed: RN6.2, U1.12
RDATA: Q5.3 (C); also elsewhere on the board
RDATA_3V3: U1.11; also elsewhere on the board
READY: Q4.3 (C); also elsewhere on the board
READY_3V3: U1.9; also elsewhere on the board
TRK0: Q2.3 (C); also elsewhere on the board
TRK0_3V3: U1.3; also elsewhere on the board
WPROT: Q3.3 (C); also elsewhere on the board
WPROT_3V3: U1.5; also elsewhere on the board

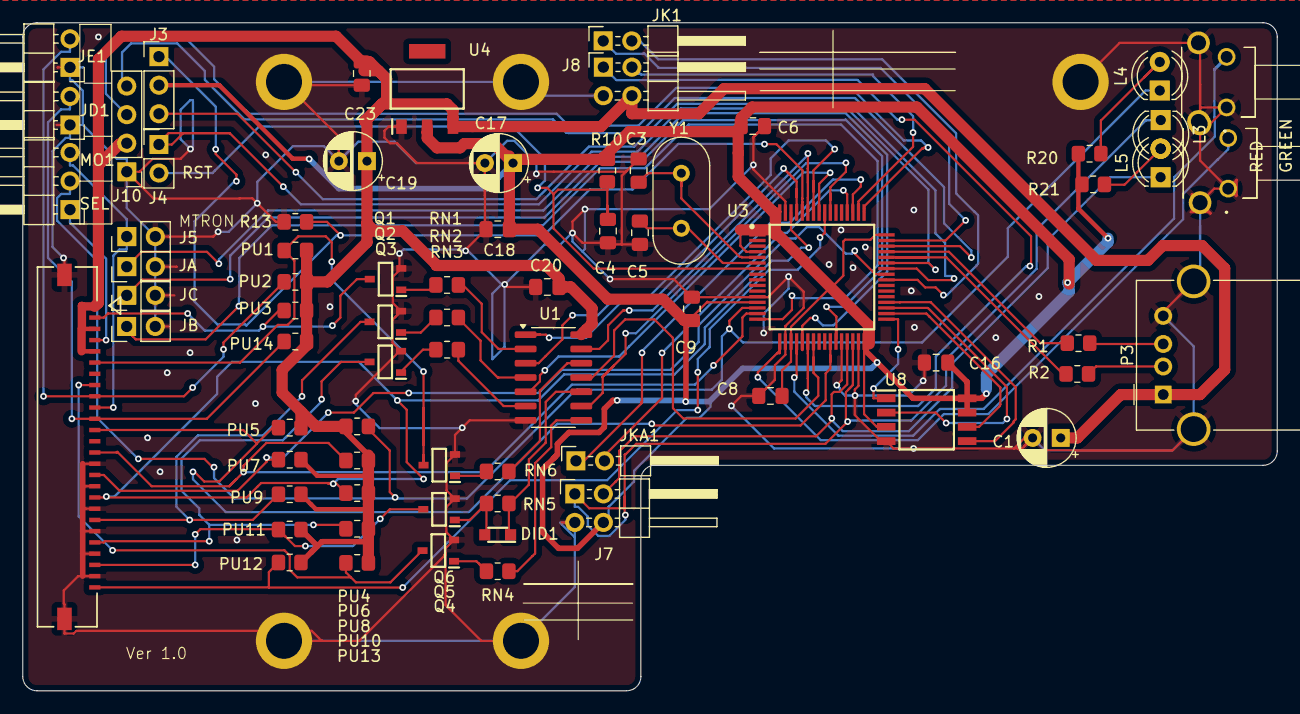
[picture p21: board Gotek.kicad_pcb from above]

Board: 2 copper layers, 111.6 x 59.4 mm, 77 parts (0 on the bottom side), 68 nets.

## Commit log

2025-03-06 Add files via upload
    Initial upload of files without component pdfs and mod/sym/stp files
    [3V3To5VConversion.kicad_sch, BOM.CSV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]
2025-03-06 Add files via upload
    Add Mod folder for Kicad. Includes kicad_mod, Kicad_sym and 3d stp/step files.
    [171826-4.stp, 1N4148WS.stp, 6101XX249121_610106249121.step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]
2025-04-11 Add files via upload
    Schematic and gerbers for a Gotek(?) compatible with an Artery AT32F435RGT7 chip and a 26 Pin FFC connector.
    Used SFRKC30.AT4.35 PCB for most of the schematic and layout but used SFRC2D.B PCB for the 26 Pin FFC connections.
    Used photographs and a multimeter along with removing U1 and U3 on the SFRKC30.AT4.35 to get to the traces underneath.
    Where possible I followed the original PCB routing of the SFRKC30.AT4.35 but Kicad has some different rules for trace widths (between pins 5&6 of U8 which isn't fitted).
    Removed L3 Green LED and changed R21 to 12K to reduce it's brightness. Also increased the pad sizes for the diode D1D to make it easier to hand solder. Minor chan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
    [3V3To5VConversion.kicad_sch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]

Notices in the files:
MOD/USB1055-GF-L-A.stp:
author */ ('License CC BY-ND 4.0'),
